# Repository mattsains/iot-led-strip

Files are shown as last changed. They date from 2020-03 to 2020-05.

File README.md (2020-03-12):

# IoT LED strip controller
An open source hardware implementation of a IoT controller for LED strips.

This board is based on an ESP32-WROOM module and can control 2 RGB(W) and one Neopixel-like strip with a supply between 5V and 24V. Each channel can sink up to 3.4A continuous through the DMN3404L driver MOSFETs.

The ESP32 allows IoT applications over the Internet (eg., Alexa, Google Home, etc) as well as over Bluetooth (eg., P2P mobile app). The ESP32 is powered through an on-board switch-mode power supply that works over the LED input voltage range of 5V to 24V.

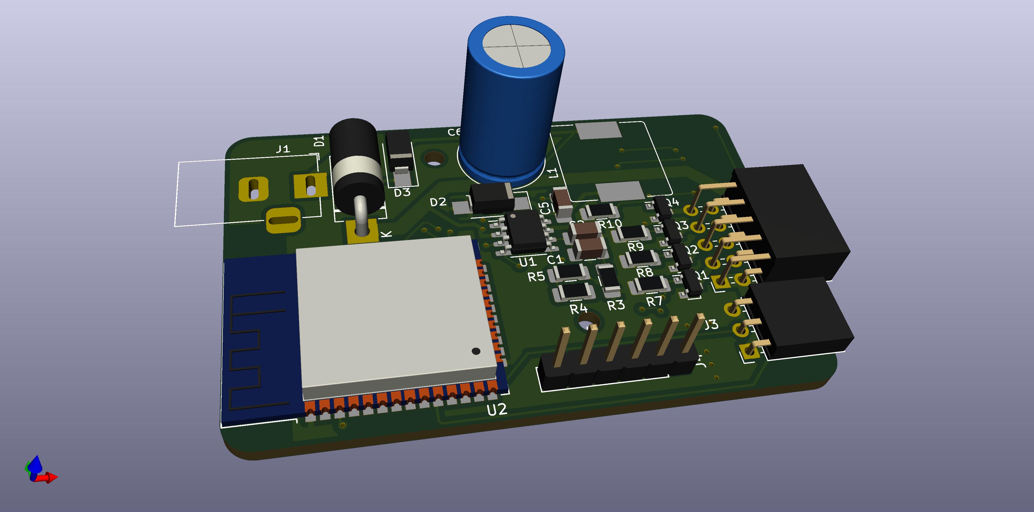
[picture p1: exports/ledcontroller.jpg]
image of controller


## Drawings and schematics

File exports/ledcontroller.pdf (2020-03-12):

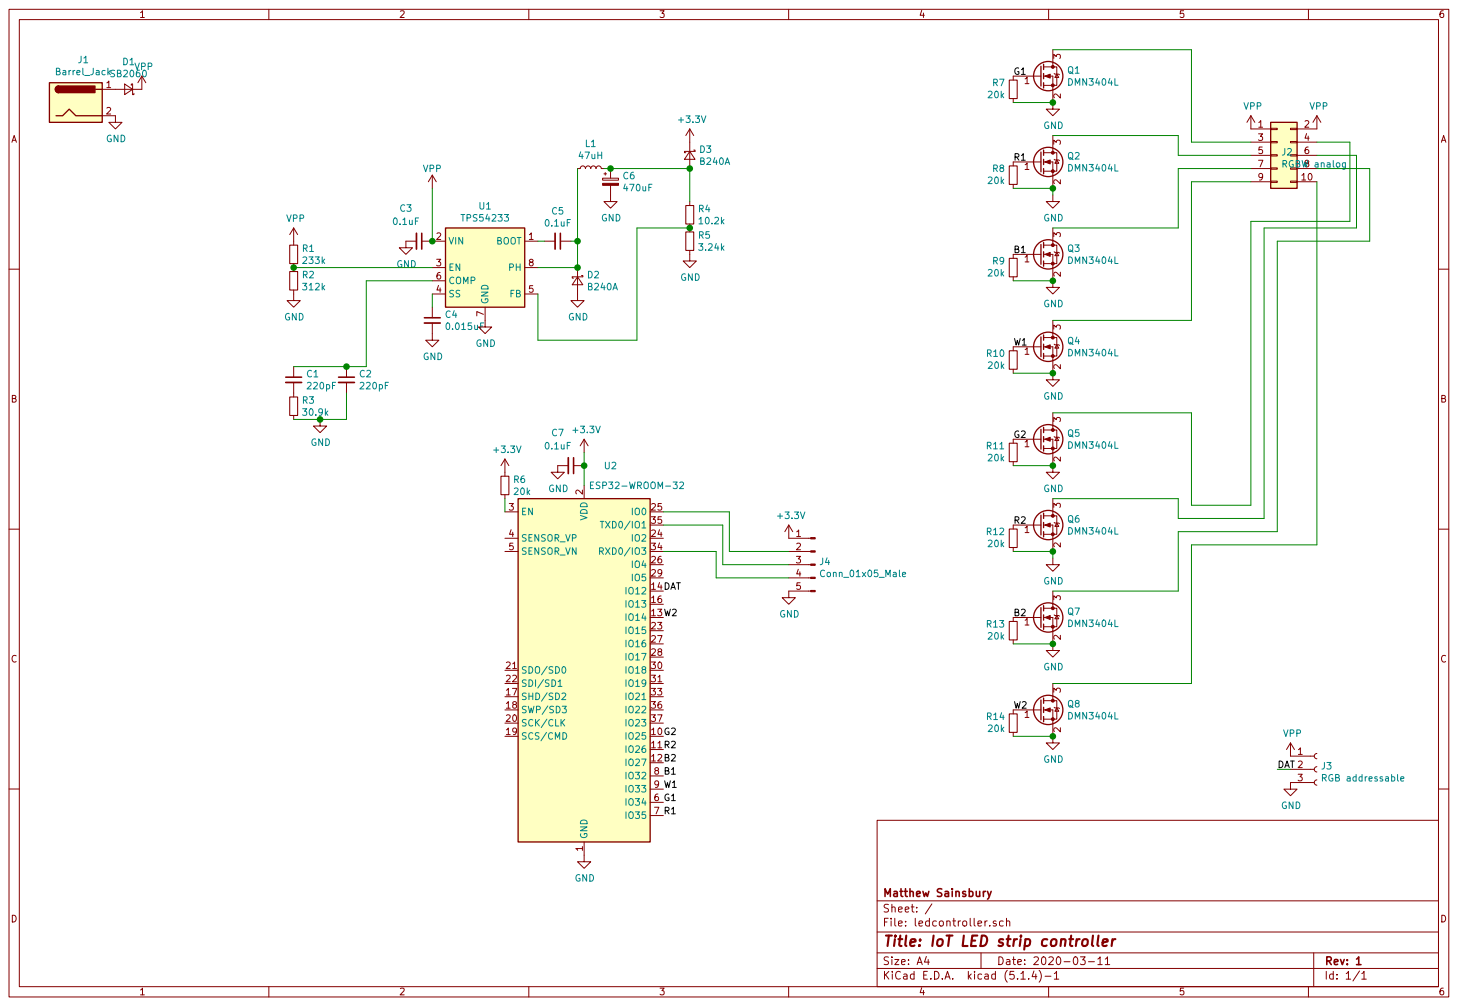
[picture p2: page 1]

Id: 1/1 Title: IoT LED strip controller File: ledcontroller.sch Sheet: / Matthew Sainsbury R14

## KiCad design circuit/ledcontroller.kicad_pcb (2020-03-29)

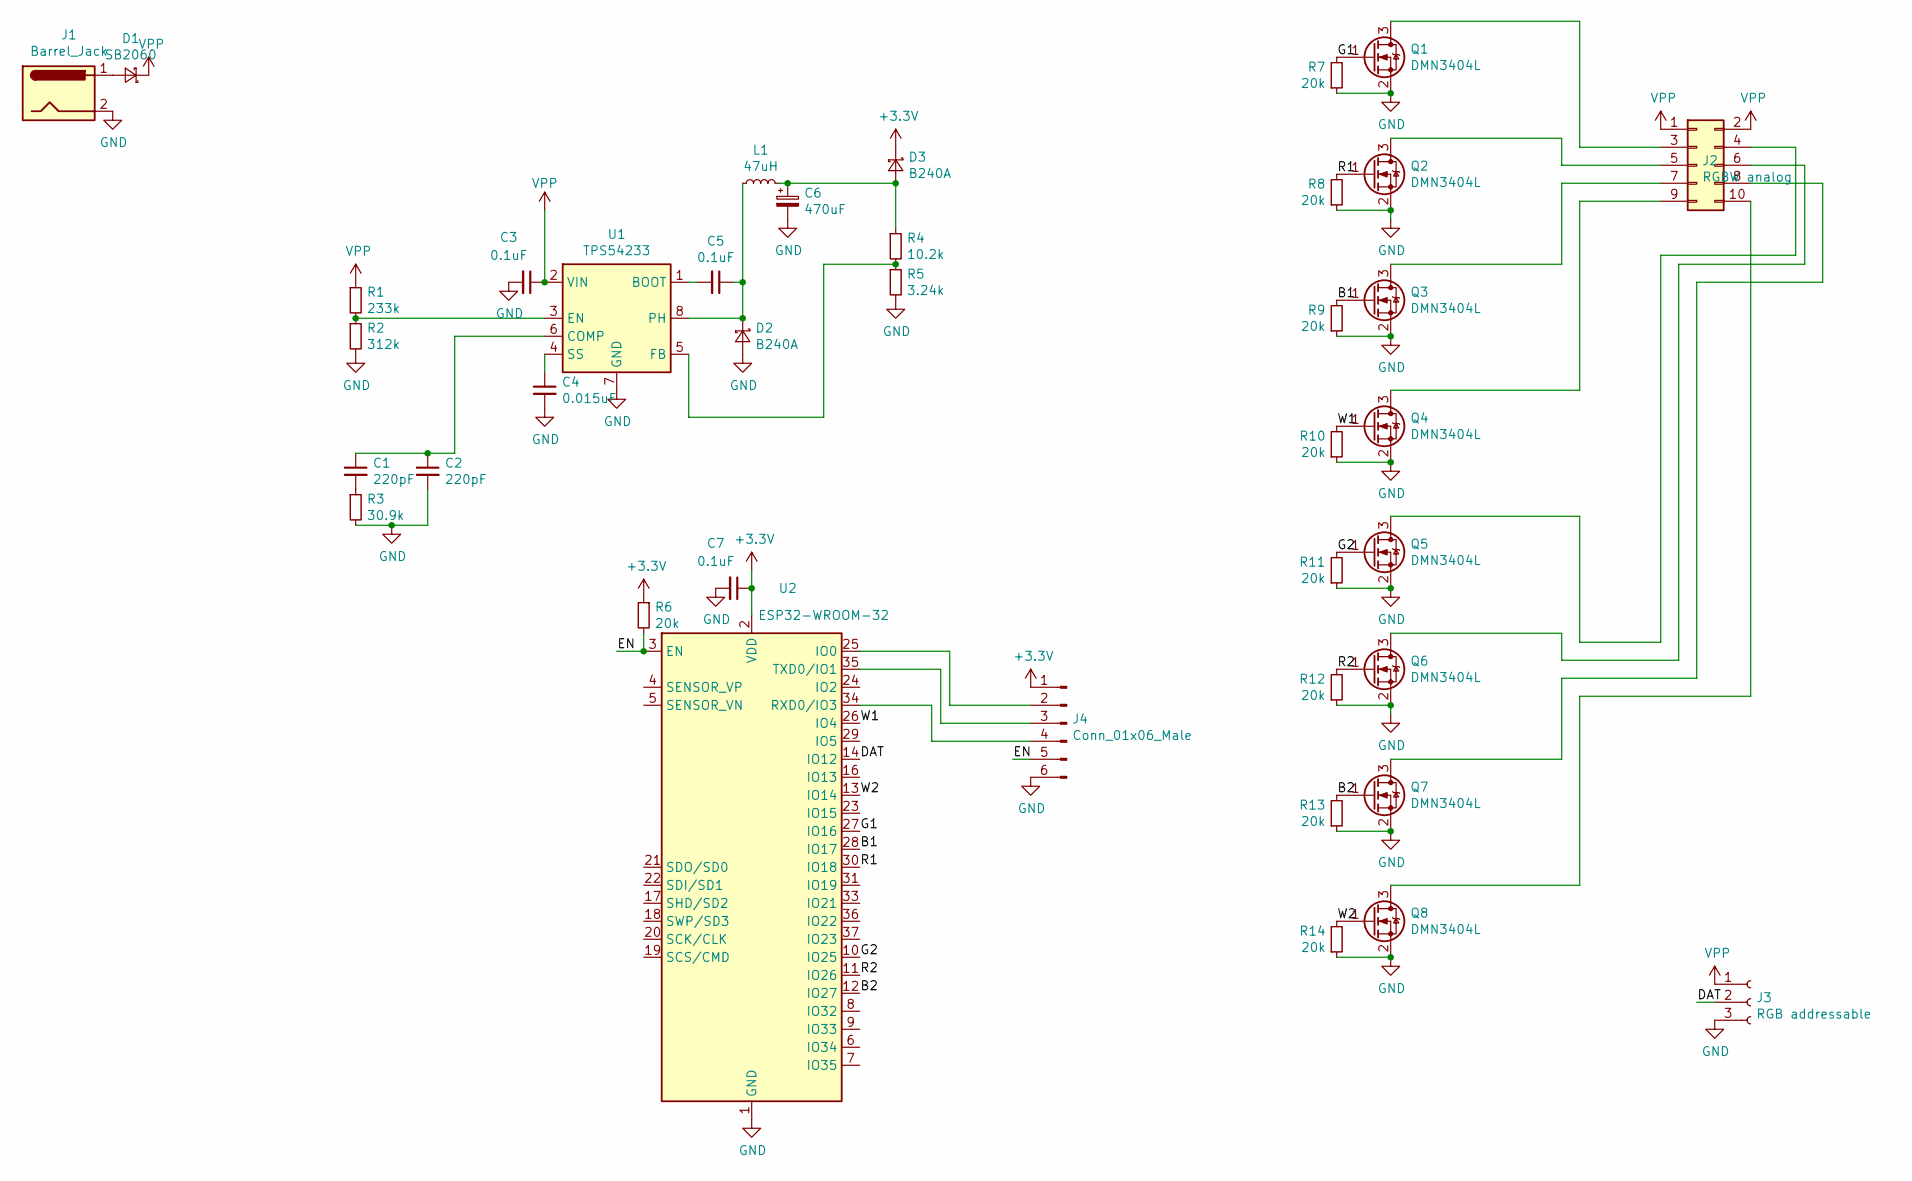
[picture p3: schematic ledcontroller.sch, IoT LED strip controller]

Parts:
C1, C2: 220pF; C_1206_3216Metric_Pad1.42x1.75mm_HandSolder
C3, C5, C7: 0.1uF; C_1206_3216Metric_Pad1.42x1.75mm_HandSolder
C4: 0.015uF; C_1206_3216Metric_Pad1.42x1.75mm_HandSolder
C6: 470uF; C_Radial_D10.0mm_H16.0mm_P5.00mm
D1: SB2060; D_DO-201AD_P12.70mm_Horizontal
D2, D3: B240A; D_SMA_Handsoldering
J1: Barrel_Jack; BarrelJack_Horizontal
J2: RGBW analog; PinSocket_2x05_P2.54mm_Horizontal
J3: RGB addressable; PinSocket_1x03_P2.54mm_Horizontal
J4: Conn_01x06_Male; PinHeader_1x06_P2.54mm_Vertical
L1: 47uH; L_Bourns_SRR1210A
Q1, Q2, Q3, Q4, Q5, Q6, Q7, Q8: DMN3404L; SOT-23
R1: 233k; R_1206_3216Metric_Pad1.42x1.75mm_HandSolder
R2: 312k; R_1206_3216Metric_Pad1.42x1.75mm_HandSolder
R3: 30.9k; R_1206_3216Metric_Pad1.42x1.75mm_HandSolder
R4: 10.2k; R_1206_3216Metric_Pad1.42x1.75mm_HandSolder
R5: 3.24k; R_1206_3216Metric_Pad1.42x1.75mm_HandSolder
R6, R7, R8, R9, R10, R11, R12, R13, R14: 20k; R_1206_3216Metric_Pad1.42x1.75mm_HandSolder
U1: TPS54233; SOIC-8_3.9x4.9mm_P1.27mm
U2: ESP32-WROOM-32

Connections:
+3V3: C7.1, D3.1 (K), J4.1, R6.1, U2.2 (VDD)
/B1: Q3.1 (G), R9.2, U2.28 (IO17)
/B2: Q7.1 (G), R13.2, U2.12 (IO27)
/DAT: J3.2, U2.14 (IO12)
/EN: J4.5, R6.2, U2.3 (EN)
/G1: Q1.1 (G), R7.2, U2.27 (IO16)
/G2: Q5.1 (G), R11.2, U2.10 (IO25)
/R1: Q2.1 (G), R8.2, U2.30 (IO18)
/R2: Q6.1 (G), R12.2, U2.11 (IO26)
/W1: Q4.1 (G), R10.2, U2.26 (IO4)
/W2: Q8.1 (G), R14.2, U2.13 (IO14)
GND: C2.2, C3.2, C4.2, C6.2, C7.2, D2.2 (A), J1.2, J3.3, J4.6, Q1.2 (S), Q2.2 (S), Q3.2 (S), Q4.2 (S), Q5.2 (S), Q6.2 (S), Q7.2 (S), Q8.2 (S), R2.2, R3.2, R5.2, R7.1, R8.1, R9.1, R10.1, R11.1, R12.1, R13.1, R14.1, U1.7 (GND), U2.1 (GND), U2.15 (GND), U2.38 (GND)
unnamed: C1.1, C2.1, U1.6 (COMP)
unnamed: C1.2, R3.1
unnamed: C4.1, U1.4 (SS)
unnamed: C5.1, D2.1 (K), L1.1, U1.8 (PH)
unnamed: C5.2, U1.1 (BOOT)
unnamed: C6.1, D3.2 (A), L1.2, R4.1
unnamed: D1.2 (A), J1.1
unnamed: J2.3, Q1.3 (D)
unnamed: J2.4, Q5.3 (D)
unnamed: J2.5, Q2.3 (D)
unnamed: J2.6, Q6.3 (D)
unnamed: J2.7, Q3.3 (D)
unnamed: J2.8, Q7.3 (D)
unnamed: J2.9, Q4.3 (D)
unnamed: J2.10, Q8.3 (D)
unnamed: J4.2, U2.25 (IO0)
unnamed: J4.3, U2.35 (TXD0/IO1)
unnamed: J4.4, U2.34 (RXD0/IO3)
unnamed: R1.2, R2.1, U1.3 (EN)
unnamed: R4.2, R5.1, U1.5 (FB)
VPP: C3.1, D1.1 (K), J2.1, J2.2, J3.1, R1.1, U1.2 (VIN)

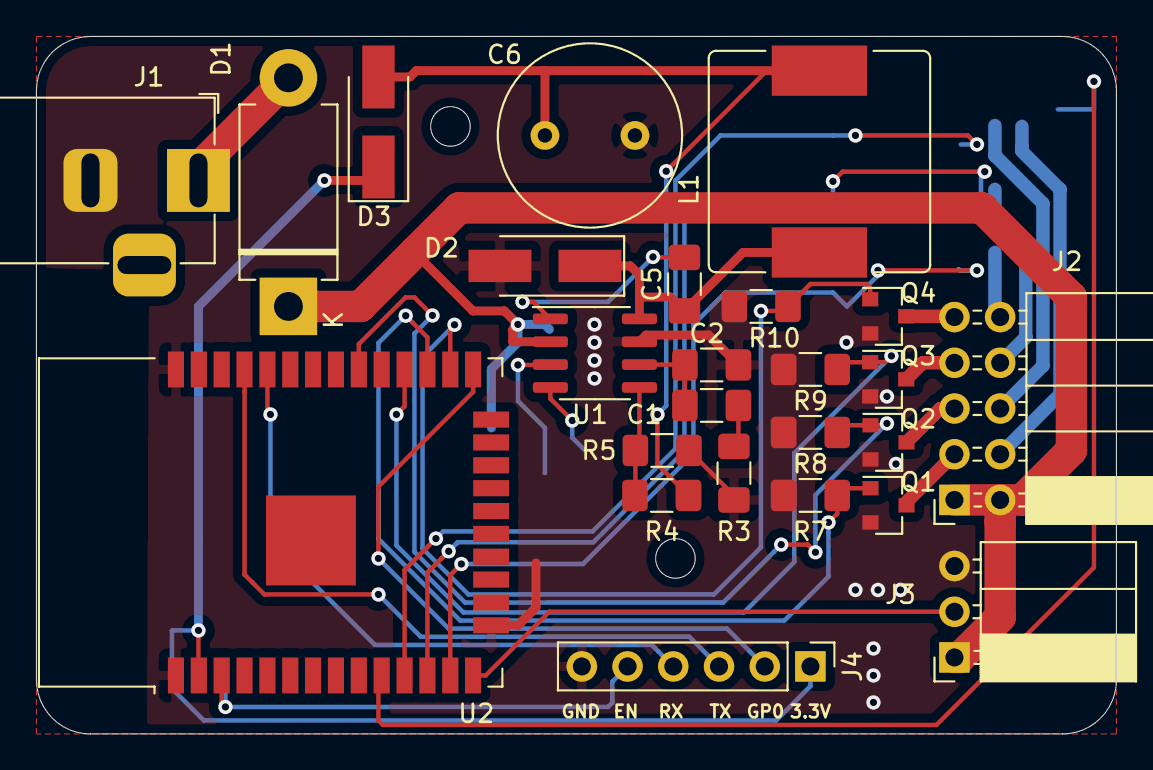
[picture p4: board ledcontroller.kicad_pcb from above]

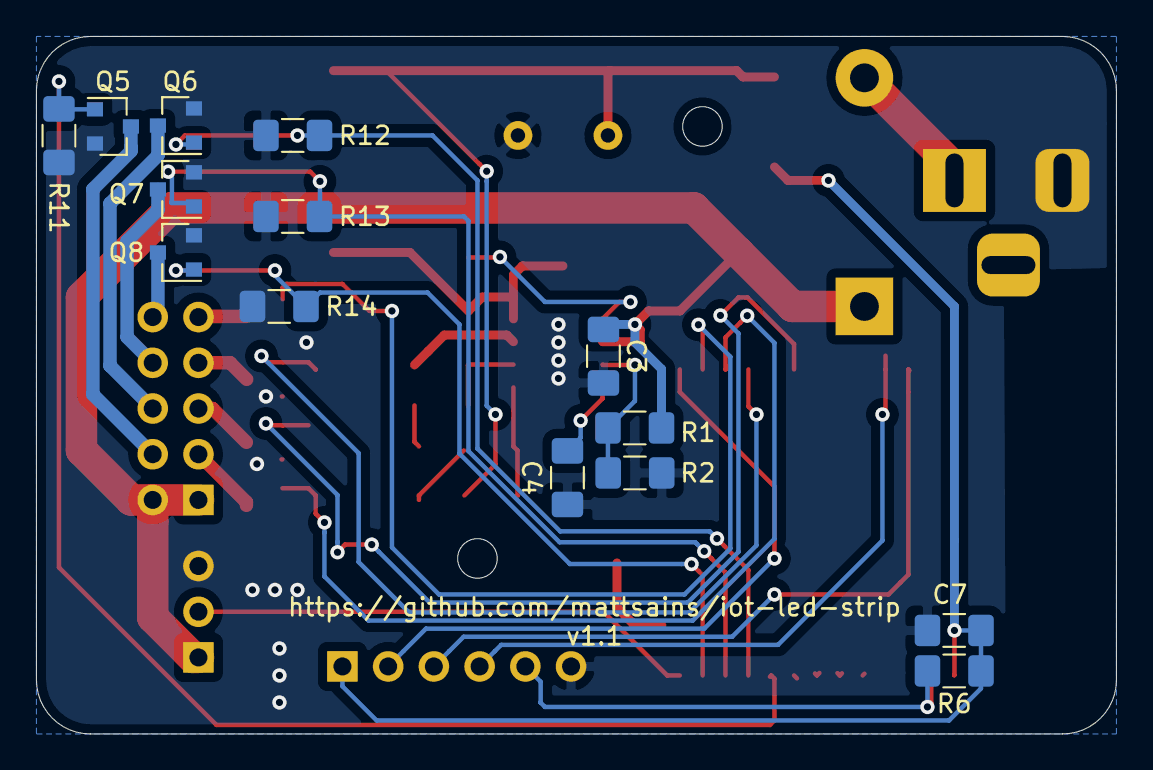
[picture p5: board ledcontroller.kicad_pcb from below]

Board: 2 copper layers, 60.0 x 38.8 mm, 41 parts (14 on the bottom side), 33 nets.

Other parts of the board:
 : MountingHole_2.2mm_M2
 #2: MountingHole_2.2mm_M2

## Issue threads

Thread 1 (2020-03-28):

Investigate slightly low VCC level

mattsains, 2020-03-28:
I measured the 3.3V supply at around 3.17V. Find out why it's lower than expected

mattsains, 2020-03-28:
I've confirmed this does not affect starting a wifi AP. So probably not a huge deal since we can provide enough power to the esp32

mattsains, 2020-05-05:
My second board doesn't have this problem, so considering this a fluke.

Closed 2020-05-05.

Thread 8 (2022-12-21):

Check that pins used of esp32 aren't problematic

mattsains, 2022-12-21:
ie., don't use strapping pins

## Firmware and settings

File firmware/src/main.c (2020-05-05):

#include "main.h"

/**
 * This method returns true if the digital LED line is pulled low.
 */
bool isResetHeld()
{
    const char ioPin = 12;
    gpio_config_t resetConfig;
    resetConfig.intr_type = GPIO_PIN_INTR_DISABLE;
    resetConfig.mode = GPIO_MODE_INPUT;
    resetConfig.pin_bit_mask = 1ULL << ioPin; // DAT pin
    resetConfig.pull_down_en = 0;
    resetConfig.pull_up_en = 1;
    gpio_config(&resetConfig);

    return gpio_get_level(ioPin) == 0;
}

void websocket_callback(int32_t event_type, char *result)
{
    char *ptr = strtok(result, ",");
    for (int i = 0; i < 8; i++)
    {
        char *endptr;
        int level = strtol(ptr, &endptr, 10);
        if (endptr == NULL) {
            ESP_LOGE("main", "Received invalid message.");
        }

        ptr = strtok(NULL, ",");

        printf("%i - ", level);
        if (i == 7)
        {
            printf("\n");
        }

        set_led(i, level);
    }
}

connection_config_t get_connection_info()
{
    connection_config_t result;

    nvs_handle_t nvs_handle;
    ESP_ERROR_CHECK(nvs_open(WIFI_NS, NVS_READWRITE, &nvs_handle));

    size_t required_size = 0;
    
    esp_err_t err = nvs_get_str(nvs_handle, WIFI_SSID, NULL, &required_size);
    if (err)
        return (connection_config_t){ };

    
    err = nvs_get_str(nvs_handle, WIFI_SSID, (char*) &result.ssid, &required_size);
    if (err)
        return (connection_config_t){ };

    required_size = 0;
    err = nvs_get_str(nvs_handle, WIFI_PASS, NULL, &required_size);
    if (err)
        return (connection_config_t){ };
    err = nvs_get_str(nvs_handle, WIFI_PASS, (char*) &result.password, &required_size);
    if (err)
        return (connection_config_t){ };

    required_size = 0;
    err = nvs_get_str(nvs_handle, API_KEY, NULL, &required_size);
    if (err)
        return (connection_config_t){ };
    err = nvs_get_str(nvs_handle, API_KEY, (char*) &result.apiKey, &required_size);
    if (err)
        return (connection_config_t){ };

    nvs_close(nvs_handle);
    return result;
}

void setup_nvr()
{
    esp_err_t ret = nvs_flash_init();
    if (ret == ESP_ERR_NVS_NO_FREE_PAGES || ret == ESP_ERR_NVS_NEW_VERSION_FOUND)
    {
        ESP_ERROR_CHECK(nvs_flash_erase());
        ret = nvs_flash_init();
    }
    ESP_ERROR_CHECK(ret);
}

static esp_err_t index_handler(httpd_req_t *req)
{
    httpd_resp_send(req, html_setup, strlen(html_setup));
    return ESP_OK;
}

static esp_err_t setup_handler(httpd_req_t *req)
{
    char *req_body = malloc(req->content_len + 1);
    {
        if (!httpd_req_recv(req, req_body, req->content_len))
        {
            httpd_resp_send_408(req);
            return ESP_OK;
        }

        req_body[req->content_len] = 0;

        ESP_LOGI("httpd", "Received something");

        // TODO: move this to a helper function.
        char ssid[32];
        char password[64];
        char apiKey[64];
        char *cert = malloc(req->content_len);

        char *acc = malloc(req->content_len);
        size_t acc_pos = 0;
        char c = req_body[0];
        char *fieldUpdating = NULL;

        for (size_t pos = 0; req_body[pos]; c = req_body[++pos])
        {
            if (c == '+')
                acc[acc_pos++] = ' ';
            else if (c == '=')
            {
                acc[acc_pos] = 0;
                acc_pos = 0;
                if (!strcmp(acc, "ssid"))
                    fieldUpdating = ssid;
                else if (!strcmp(acc, "password"))
                    fieldUpdating = password;
                else if (!strcmp(acc, "apikey"))
                    fieldUpdating = apiKey;
                else if (!strcmp(acc, "cert"))
                    fieldUpdating = cert;
                else
                    fieldUpdating = NULL;
            }
            else if (c == '%')
            {
                char num_c[3];
                num_c[0] = req_body[++pos];
                num_c[1] = req_body[++pos];
                num_c[2] = 0;
                acc[acc_pos++] = strtol(num_c, NULL, 16);
            }
            else if (c == '&')
            {
                acc[acc_pos] = 0;
                acc_pos = 0;
                if (fieldUpdating != NULL)
                {
                    strcpy(fieldUpdating, acc);
                }
            }
            else
                acc[acc_pos++] = c;
        }
        acc[acc_pos] = 0;
        acc_pos = 0;
        if (fieldUpdating != NULL)
        {
            strcpy(fieldUpdating, acc);
        }
        free(acc);
        free(cert);

        //ESP_LOGI("httpd", "Received: %s", req_body);
        ESP_LOGI("httpd", "Received SSID: '%s'", ssid);
        ESP_LOGI("httpd", "Received password: '%s'", password);
        ESP_LOGI("httpd", "Received api key: '%s'", apiKey);
        //ESP_LOGI("httpd", "Received cert: '%s'", cert);

        nvs_handle_t nvs_handle;
        ESP_ERROR_CHECK(nvs_open(WIFI_NS, NVS_READWRITE, &nvs_handle));

        nvs_set_str(nvs_handle, WIFI_SSID, ssid);
        nvs_set_str(nvs_handle, WIFI_PASS, password);
        nvs_set_str(nvs_handle, API_KEY, apiKey);
        nvs_set_str(nvs_handle, CERT, cert);
        nvs_commit(nvs_handle);
    }
    free(req_body);

    const char *thanks = "<h1>Thanks!</h1>";
    httpd_resp_send(req, thanks, strlen(thanks));

    esp_restart();
    return ESP_OK;
}

static httpd_uri_t routes[2] = {{
                                    .uri = "/",
                                    .method = HTTP_GET,
                                    .handler = index_handler,
                                },
                                {
                                    .uri = "/setup",
                                    .method = HTTP_POST,
                                    .handler = setup_handler,
                                }};

void app_main(void)
{
    if (isResetHeld())
    {
        // erase the nvr so we can re-configure the device
        ESP_LOGI("nvs", "Erasing the nvs because reset is low");
        ESP_ERROR_CHECK(nvs_flash_erase());
    }

    setup_nvr();
    setup_leds();

    connection_config_t load_config_result = get_connection_info();

    if (load_config_result.ssid[0] == 0)
    {
        // if there's no wifi configuration, assume that it's the first run of this device, and enter setup mode.
        wifi_ap_start(routes, sizeof(routes) / sizeof(routes[0]));
    }
    else
    {
        wifi_sta_config_t wifiConfig = {
            .ssid = "",
            .password = ""};
        strcpy((char *)wifiConfig.ssid, load_config_result.ssid);
        strcpy((char *)wifiConfig.password, load_config_result.password);
        ESP_ERROR_CHECK(wifi_connect(wifiConfig));

        establish_websocket("wss://iot.sainsbury.io:443/ws", load_config_result.apiKey, load_config_result.sslCert, websocket_callback);
    }

    while (1)
    {
        vTaskDelay(1000000 / portTICK_PERIOD_MS);
    }
}

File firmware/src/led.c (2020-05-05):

#include "led.h"

static ledc_channel_config_t ledc_channel[8];

void setup_leds(void)
{
    ledc_timer_config_t ledc_timer = {
        .duty_resolution = LEDC_TIMER_11_BIT,
        .freq_hz = 20000,
        .speed_mode = LEDC_LOW_SPEED_MODE,
        .timer_num = LEDC_TIMER_1,
        .clk_cfg = LEDC_AUTO_CLK,
    };

    ledc_timer_config(&ledc_timer);

    // LED 0
    ledc_channel[0] = (ledc_channel_config_t){
        .channel = LEDC_CHANNEL_0,
        .duty = 0,
        .gpio_num = LED_0_W,
        .speed_mode = LEDC_LOW_SPEED_MODE,
        .hpoint = 0,
        .timer_sel = LEDC_TIMER_1};
    ledc_channel[1] = (ledc_channel_config_t){
        .channel = LEDC_CHANNEL_1,
        .duty = 0,
        .gpio_num = LED_0_R,
        .speed_mode = LEDC_LOW_SPEED_MODE,
        .hpoint = 0,
        .timer_sel = LEDC_TIMER_1};

    ledc_channel[2] = (ledc_channel_config_t){
        .channel = LEDC_CHANNEL_2,
        .duty = 0,
        .gpio_num = LED_0_G,
        .speed_mode = LEDC_LOW_SPEED_MODE,
        .hpoint = 0,
        .timer_sel = LEDC_TIMER_1};

    ledc_channel[3] = (ledc_channel_config_t){
        .channel = LEDC_CHANNEL_3,
        .duty = 0,
        .gpio_num = LED_0_B,
        .speed_mode = LEDC_LOW_SPEED_MODE,
        .hpoint = 0,
        .timer_sel = LEDC_TIMER_1};

    // LED 1
    ledc_channel[4] = (ledc_channel_config_t){
        .channel = LEDC_CHANNEL_0,
        .duty = 0,
        .gpio_num = LED_1_W,
        .speed_mode = LEDC_LOW_SPEED_MODE,
        .hpoint = 0,
        .timer_sel = LEDC_TIMER_1};
    ledc_channel[5] = (ledc_channel_config_t){
        .channel = LEDC_CHANNEL_1,
        .duty = 0,
        .gpio_num = LED_1_R,
        .speed_mode = LEDC_LOW_SPEED_MODE,
        .hpoint = 0,
        .timer_sel = LEDC_TIMER_1};

    ledc_channel[6] = (ledc_channel_config_t){
        .channel = LEDC_CHANNEL_2,
        .duty = 0,
        .gpio_num = LED_1_G,
        .speed_mode = LEDC_LOW_SPEED_MODE,
        .hpoint = 0,
        .timer_sel = LEDC_TIMER_1};

    ledc_channel[7] = (ledc_channel_config_t){
        .channel = LEDC_CHANNEL_3,
        .duty = 0,
        .gpio_num = LED_1_B,
        .speed_mode = LEDC_LOW_SPEED_MODE,
        .hpoint = 0,
        .timer_sel = LEDC_TIMER_1};

    for (uint8_t i = 0; i < 8; i++)
    {
        ledc_channel_config(&ledc_channel[i]);
    }

    ledc_fade_func_install(0);

    // set up ws2381 strip
    rmt_config_t config = {
        .rmt_mode = RMT_MODE_TX,
        .channel = RMT_CHANNEL_0,
        .clk_div = 1,
        .gpio_num = LED_2_DAT,
        .mem_block_num = 1,
        .tx_config = {
            .carrier_freq_hz = 0,
            .carrier_level = RMT_CARRIER_LEVEL_HIGH,
            .idle_level = RMT_IDLE_LEVEL_LOW,
            .carrier_duty_percent = 33,
            .carrier_en = false,
            .loop_en = false,
            .idle_output_en = true,
        }};

    rmt_config(&config);
    rmt_driver_install(RMT_CHANNEL_0, 0, 0);
}

void set_led(uint8_t led, uint32_t level)
{
    int actual = (level * 2047) / 1000;
    ledc_set_fade_with_time(ledc_channel[led].speed_mode, ledc_channel[led].channel, actual, 500);
    ledc_fade_start(ledc_channel[led].speed_mode, ledc_channel[led].channel, LEDC_FADE_NO_WAIT);
}

void deallocate_tx_buffer(rmt_channel_t channel, void *buffer) {
    free(buffer);
}

void set_strip(uint8_t *data, size_t num_bytes)
{
    rmt_item32_t *outBuffer = malloc((8 * num_bytes + 1) * sizeof(rmt_item32_t));

    for (size_t i = 0; i < num_bytes; i++)
    {
        uint8_t b = data[i];
        for (uint8_t j = 0; j < 8; j++)
        {
            if (b && (1 << j) != 0)
            {
                outBuffer[i * 8 + j] = (rmt_item32_t){{{65, 1, 36, 0}}};
            }
            else
            {
                outBuffer[i * 8 + j] = (rmt_item32_t){{{32, 1, 69, 0}}};
            }
        }
    }
    outBuffer[num_bytes * 8] = (rmt_item32_t){{{2419, 0, 2419, 0}}};

    rmt_register_tx_end_callback(&deallocate_tx_buffer, outBuffer);
    rmt_write_items(RMT_CHANNEL_0, outBuffer, 1, false);
}

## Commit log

2020-03-12 Initial design done
    [ledcontroller.kicad_pcb, ledcontroller.sch]
2020-03-12 Added exports directory
    [ledcontroller.sch]
2020-03-14 Increase track width for power; release v1
    [ledcontroller.kicad_pcb]
2020-03-28 fixes #4 #3 #2
    [ledcontroller.kicad_pcb, ledcontroller.sch]
2020-03-29 respin for v1.1
    [ledcontroller.kicad_pcb]
2020-04-27 Refactor firmware and fix server bug
    [led.c, main.c]
2020-05-01 Move circuit design to subdirectory
    [ledcontroller.kicad_pcb, ledcontroller.sch]
2020-05-05 Write draft of addressable strip control, and fix https implementation
    [led.c, led.h, main.c]
